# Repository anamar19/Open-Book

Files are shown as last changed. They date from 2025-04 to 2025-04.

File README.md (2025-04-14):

# 1. Block Diagram #


# 2. Bill of Materials (BOM) #
| Ref | Component | Link | Datasheet |
|-----|---|---|---|
| J2 | USB4110-GF-A | [LINK](https://ro.mouser.com/ProductDetail/GCT/USB4110-GF-A?qs=KUoIvG%2F9IlYiZvIXQjyJeA%3D%3D) | [DATASHEET](https://ro.mouser.com/datasheet/2/837/GCT_USB4110_Product_Drawing___20k_cycles-3455479.pdf) |
| D1 | USBLC6-2SC6Y |[LINK](https://ro.mouser.com/ProductDetail/STMicroelectronics/USBLC6-2SC6Y?qs=gNDSiZmRJS%2FOgDexvXkdow%3D%3D) | [DATASHEET](https://ro.mouser.com/datasheet/2/389/usblc6_2sc6y-1852505.pdf) |
| PFMF.050.2 | PFMF.050.2 | [LINK](https://ro.mouser.com/ProductDetail/Schurter/PFMF.010.2?qs=1auRipcfynCnJdD0clLSNw%3D%3D) | [DATASHEET](https://ro.mouser.com/datasheet/2/358/typ_PFMF-1275918.pdf) |
| C | C0402 | [LINK](https://ro.mouser.com/ProductDetail/KEMET/C0402C475K8PACTU?qs=ulEaXIWI0c9ebKRT3r3htg%3D%3D) | [DATASHEET](https://ro.mouser.com/datasheet/2/447/KEM_C1006_X5R_SMD-3316465.pdf) |
| R | CR0402 | [LINK](https://ro.mouser.com/ProductDetail/Bourns/CR0402-FX-78R7GLF?qs=ePR1ZvdkOKLVu%2FTT5yAHeA%3D%3D) |[DATASHEET](https://ro.mouser.com/datasheet/2/54/cr-1858361.pdf) |
| Q1 | DMG2305UX-7 | [LINK](https://ro.mouser.com/ProductDetail/Diodes-Incorporated/DMG2305UX-7?qs=L1DZKBg7t5F%2FNBHrjfxC%252Bg%3D%3D) | [DATASHEET](https://www.diodes.com/assets/Datasheets/DMG2305UX.pdf) |
| D2 | SD0805S020S1R0 | [LINK](https://eu.mouser.com/ProductDetail/KYOCERA-AVX/SD0805S020S1R0?qs=jCA%252BPfw4LHbpkAoSnwrdjw%3D%3D) | [DATASHEET](https://eu.mouser.com/datasheet/2/40/schottky-3165252.pdf) |
| C3 | F910J107MBAAJ6 | [LINK](https://eu.mouser.com/ProductDetail/KYOCERA-AVX/F910J107MBAAJ6?qs=PqoDHHvF649LraCA%2FjeGXg%3D%3D) | [DATASHEET](https://eu.mouser.com/datasheet/2/40/F91_AJ6-3162641.pdf) |
| IC1 | BD5229G-TR | [LINK](https://ro.mouser.com/ProductDetail/ROHM-Semiconductor/BD5229G-TR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) | [DATASHEET](https://fscdn.rohm.com/en/products/databook/datasheet/ic/power/voltage_detector/bd52xxg-e.pdf) |
| J4 | 112A-TAAR-R03 | [LINK](https://store.comet.srl.ro/Catalogue/Product/43497/) |[DATASHEET](https://www.attend.com.tw/data/download/file/112A-TAAR-R03.rar) |
| U2 | ESP32-C6-WROOM-1-N8 | [LINK](https://componentsearchengine.com/prices/ESP32-C6-WROOM-1-N8?manufacturer=Espressif%20Systems) | [DATASHEET](https://www.espressif.com/sites/default/files/documentation/esp32-c6-wroom-1_wroom-1u_datasheet_en.pdf) |
| U4 | MAX17048G+T10 | [LINK](https://ro.mouser.com/ProductDetail/Analog-Devices-Maxim-Integrated/MAX17048G%2bT10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) | [DATASHEET](https://ro.mouser.com/datasheet/2/609/MAX17048_MAX17049-3469099.pdf) |
| BUTTON | KMR221GULCLFS | [LINK](https://ro.mouser.com/ProductDetail/CK/KMR221GULCLFS?qs=u2NJ%252B70r0goBXaNk7IrU0Q%3D%3D) | [DATASHEET](https://www.ckswitches.com/media/1479/kmr2.pdf )|
| IC5 | BD5229G-TR | [LINK](https://ro.mouser.com/ProductDetail/ROHM-Semiconductor/BD5229G-TR?qs=4kLU8WoGk0vvnhrrYwdszw%3D%3D)  | [DATASHEET](https://fscdn.rohm.com/en/products/databook/datasheet/ic/power/voltage_detector/bd52xxg-e.pdf) |
| MCP | MCP73831T-2ACI/OT | [LINK](https://ro.mouser.com/ProductDetail/Microchip-Technology/MCP73831T-2ACI-OT?qs=yUQqVecv4qvbBQBGbHx0Mw%3D%3D)) | [DATASHEET](https://ro.mouser.com/datasheet/2/268/MCP73831_Family_Data_Sheet_DS20001984H-3441711.pdf)|
| Q3 | SI1308EDL-T1-GE3 | [LINK](https://componentsearchengine.com/prices/Si1308EDL-T1-GE3?manufacturer=Vishay) | [DATASHEET](https://componentsearchengine.com/Datasheets/1/SI1308EDL-T1-GE3.pdf) |
| SENSOR2 | BME680 | [LINK](https://ro.mouser.com/ProductDetail/Bosch-Sensortec/BME680?qs=v271MhAjFHjo0yA%2FC4OnDQ%3D%3D)  | [DATASHEET](https://ro.mouser.com/datasheet/2/783/BST_BME680_DS001-1509608.pdf) |
| SJ1 | CJS-1201B | [LINK](https://ro.mouser.com/ProductDetail/Nidec-Components/CJS-1201B?qs=XeJtXLiO41SSSa2Z7HG9Iw%3D%3D)  | [DATASHEET](https://ro.mouser.com/datasheet/2/972/cjs-1827353.pdf) |
| L1 |  LQW18ANR18J00D| [LINK](https://ro.mouser.com/ProductDetail/Murata-Electronics/LQW18ANR18J00D?qs=up2IPS6mPfZTlRcpK55RLw%3D%3D)  | [DATASHEET](https://ro.mouser.com/datasheet/2/281/JELF243A_0024-1380895.pdf) |
| D3 | MBR0530T3G | [LINK](https://ro.mouser.com/ProductDetail/onsemi/MBR0530T3G?qs=3JMERSakebpEmdUS6GetdQ%3D%3D)  | [DATASHEET](https://www.onsemi.com/PowerSolutions/product.do?id=MBR0530T3G) |
| J1 | FH34SRJ-24S-0.5SH_99_ | [LINK](https://ro.mouser.com/ProductDetail/Hirose-Connector/FH34SRJ-24S-0.5SH99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)  | [DATASHEET](https://ro.mouser.com/datasheet/2/185/FH34SRJ_24S_0_5SH_99__CL0580_1255_6_99_2DDrawing_0-1615044.pdf) |
| U3 | DS3231SN# | [LINK](https://ro.mouser.com/ProductDetail/Analog-Devices-Maxim-Integrated/DS3231SN?qs=1eQvB6Dk1vhUlr8%2FOrV0Fw%3D%3D)  | [DATASHEET](https://ro.mouser.com/datasheet/2/609/DS3231-3421123.pdf) |
|C10_SUPERCAR | CPH3225A | [LINK](https://ro.mouser.com/ProductDetail/Seiko-Semiconductors/CPH3225A?qs=3etwrb1wR%252BhUOph6lAO7eg%3D%3D)  | [DATASHEET](https://ro.mouser.com/datasheet/2/360/Seiko_Instruments_MicroBattery_E_20230330_2024Jan_-3561061.pdf) |
| D8 | PGB1010603MR | [LINK](https://ro.mouser.com/ProductDetail/Littelfuse/PGB1010603MR?qs=gu7KAQ731URLg4GSnNNN7Q%3D%3D) | [DATASHEET](https://www.littelfuse.com/assetdocs/pulseguard-esd-suppressors-pgb1-datasheet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) |
| J3 | 4208| [LINK](https://ro.mouser.com/ProductDetail/Adafruit/4208?qs=PzGy0jfpSMtbScLbr0L5dw%3D%3D) | [DATASHEET](https://www.analog.com/media/en/technical-documentation/data-sheets/ada4570.pdf) |
| U1 | W25Q512JVEIQ | [LINK](https://ro.mouser.com/ProductDetail/Winbond/W25Q512JVEIQ?qs=l7cgNqFNU1jw6svr3at6tA%3D%3D) | [DATASHEET](https://ro.mouser.com/datasheet/2/949/Winbond_W25Q512JV_Datasheet-3240039.pdf) |

# 3. Funcționalități Hardware #

## 3.1. Componente, module și senzori ##

### ESP32-C6-WROOM-1-N8 ###
- microcontroler de bază care gestionează comunicațiile(SPI,I2C), controlează perifericele.
### USB C connector & ESD protection ###
- asigură alimentarea prin USB-C și protecție.
### LDO Voltage Regulator ###
- stabilizează tensiunea de 3.3V
### SD Card ###
- permite stocarea locală a fișierelor de configurare și a datelor.
### E-Paper Drive Circuit & Header ###
- generează semnale pentru controlul ecranului E-Paper și permite selectarea tipului de dispaly.
### Li-Po Battery Charging Controller ###
- încarcă bateria Li-Po și gestionează curentul de încărcare.
### Environmental Sensor  ###
- măsoară presiunea, temperatura, umiditatea și calitatea aerului.
### Voltage Supervisor + Reset & Boot / IO Button ###
- monitorizează tensiunea de alimentare și asigură resetarea sistemului.
### Li-Po Battery ###
- sursă de alimentare de rezervă, care permite funcționarea sistemului fără USB.
### RTC Module DS3231SN ###
- asigură funcționarea de ceas în timp real.
### External NORFlash64MB ###
- memorie secundară pentru stocarea datelor.

## 3.2. Specificații de comunicație ##
- SPI este folosit pentru NOR Flash, cardul SD și dispaly-ul E-Paper
- I2C este utilizat pentru senzorul BME688 și modulul DS3231SN
- UART este folosit pentru debugging
- Wi-Fi & Bluetooth LE sunt date de ESP32-C6 pentru conectivitate wireless.

## 3.3. Calcule de consum de energie ##
- ESP32-C6: consum în mod activ-aprox 80-240mA și în mod sleep-cam 1mA
- NOR Flash: consum la citire/scriere-5-15mA, iar în repaus-mai puțin de 10uA
- BM3688: consum în mod activ de 3.1mA, iar în mod sleep aprox 2.1uA
- LDO: eficiența depinde de diferența de tensiune (aprox 3.3V) și curentul total
- DS3231SN: consum de cca 150uA cu backup la baterie

  Bateria Li-Po poate menține sistemul destul de mult timp, de ordinul zilelor chiar, în funcție de capacitate și de cât de des se folosesc comunicațiile Wi-Fi/Bluetooth.

# 4. Pinii ESP32-C6 #
| Pin | Componentă | Motiv |
|-----|---|---|
| MOSI(IO6) | SPI MOSI către NOR Flash,SD Card și E-Paper | Transfer date către periferice SPI |
| MISO(IO7) | SPI MISO din NOR Flash,SD Card și E-Paper | Primire date către periferice SPI |
| SDA(IO14) | I2C SDA către BME688 și DS3231SN | Linia de date pentru I2C|
| SCL(IO15) | I2C SCL către BME688 și DS3231SN | Semnal de clock I2C |
| SCK(IO8) | SPI Clock | Semnal de clock SPI |
| CS1(IO9) |  Chip Select NOR Flash | Control dedicat pentru NOR Flash |
| CS2(IO10) |  Chip Select E-Paper Display | Control dedicat pentru Display |
| CS3(IO11) | Chip Select SD Card |  Control dedicat pentru SD Card |
| IO16,IO17 | UART,TX,RX(debug) | Debug serial și programare |
| IO21 | Control Boot/Reset | Butoane de reset și boot |
| 3V3(IO2) | - | Furnizează tensiunea de 3.3V pentru componente |
| GND | - | Referință pentru circuit |

# 5. Comentarii #
## 5.1. Design log și Randări PCB ##
Randări:
- există randări 3D ale PCB-ULUI care arată poziționarea corectă a componentelor pricipale: ESP32-C6, conectorul USB, senzorii
- carcasa este proiectată în Fusion 360
- bateria este proiectată, de asemenea, în Fusion 360
-  display-ul este luat din [link](https://grabcad.com/library/7-5in-e-ink-display-assortment-1) conform datasheet-ului

## 5.2. Așezarea Componentelor în Carcasă ##
- Conectorii Qwiic/ Stemma QT  sunt plasați la marfinea plăcii pentru a facilita atașarea rapidă a altor senzori
- Bateria Li-Po e plasată direct lângă PCB pentru a economisi spațiu
- Microcontrolerul ESP32 e poziționat la marginea PCB-ului pentru a reduce interferențele la antenă, iar din această cauză a fost tăiat și planul de masă li placa PCB în jurul antenei

## 5.3. Decizii luate ##
Am acceptat cele 7 erori de overlap pentru că traseele de putere, fiind rutate cu 0.3mm, se intersecteaza pe padul B9:VBUS și A4:VUSB, acestea fiind foarte apropiate una de alta.  Mai am 2 erori de Board Outline Clearance la aceeasi componenta, pe care le-am acceptat pentru ca așa este configurată componenta USB4110-GF-A, adica din cauza dimensiunii gaurilor.

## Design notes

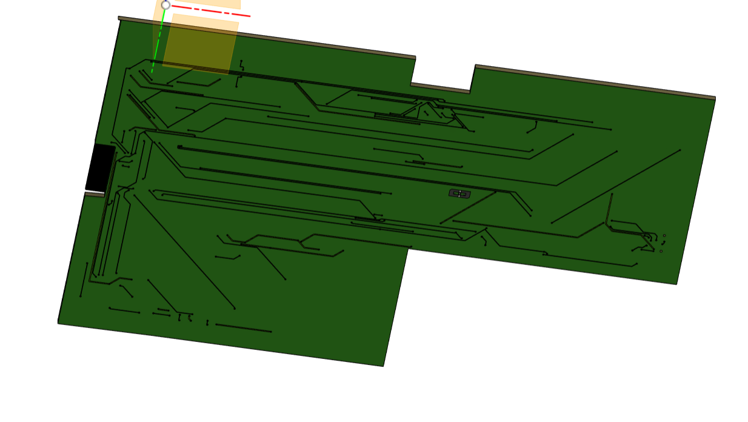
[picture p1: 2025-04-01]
Images/PCB2.png

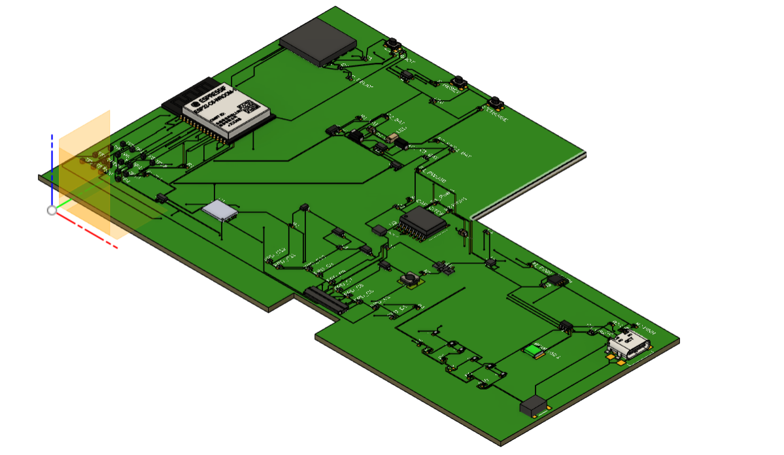
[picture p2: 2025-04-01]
Images/PCB1.png

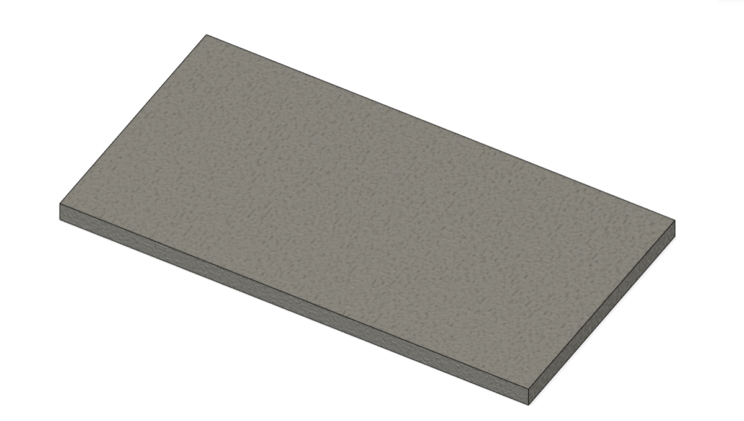
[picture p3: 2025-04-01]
Images/Battery.png

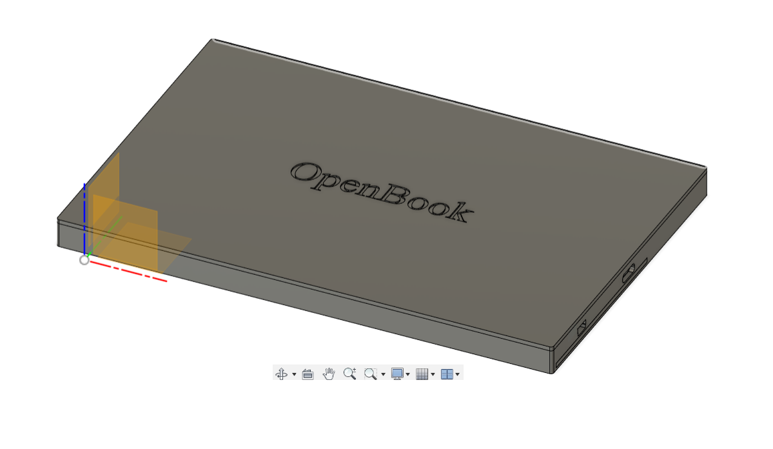
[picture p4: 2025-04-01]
Images/Device2.png

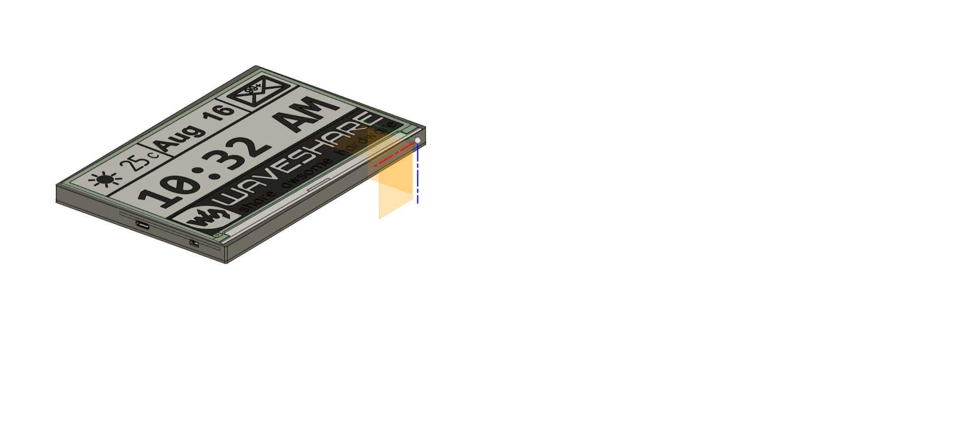
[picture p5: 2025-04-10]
Images/Device1.png

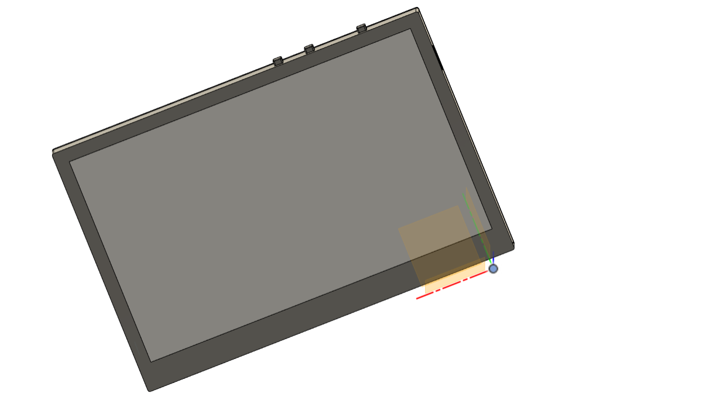
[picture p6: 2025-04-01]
Images/Dispaly.png

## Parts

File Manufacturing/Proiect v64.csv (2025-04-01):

Qty | Value | Device | Package | Parts | Description | ARROW_PART_NUMBER | ARROW_PRICE-STOCK | AVAILABILITY | CATEGORY | CENTROID_NOT_SPECIFIED | CHECK_PRICES | COPYRIGHT | DATASHEET | DESCRIPTION | DIGIKEY_DESCRIPTION | DIGIKEY_PART_NUMBER | HEIGHT | LEAD_FREE | MANUFACTURER | MANUFACTURER_NAME | MANUFACTURER_PART_NUMBER | MF | MFR_NAME | MOUSER_PART_NUMBER | MOUSER_PRICE-STOCK | MP | MPN | OPERATING_TEMPERATURE | PACKAGE | PACKAGE_SIZE | PACKAGE_TYPE | PART_STATUS | POPULARITY | PREFIX | PRICE | PROD_ID | PURCHASE-URL | ROHS | SERIES | SNAPEDA_LINK | SPICEMODEL | SPICEPREFIX | SUBCATEGORY | TEMPERATURE_RANGE_HIGH | TEMPERATURE_RANGE_LOW | THERMALLOSS | TOLERANCE | TP_SIGNAL_NAME | TYPE | VALUE | VOLTAGE_RATING
1 |  | ADAFRUIT_LEDCHIP-LED0603 | ADAFRUIT_CHIP-LED0603 | CHG_LED | LED
1 |  | SJ | SJ | SJ1 | SMD solder JUMPER |  |  |  |  |  |  |  |  |  |  |  |  |  |  |  |  |  |  |  |  |  |  |  |  |  |  |  | 3
1 | 0.1uF/50V | ESP32_WROVER_EAGLE-LTSPICE_CC0402 | ESP32_WROVER_EAGLE-LTSPICE_C0402 | EPD_C5 | CAPACITOR, European symbol |  |  |  |  |  |  |  |  |  |  |  |  |  |  |  |  |  |  |  |  |  |  |  |  |  |  |  |  |  |  |  |  |  |  |  | NONE | C
1 | 0.47 | ESP32_WROVER_EAGLE-LTSPICE_RR0402 | ESP32_WROVER_EAGLE-LTSPICE_R0402 | R3 | RESISTOR, European symbol |  |  |  |  |  |  |  |  |  |  |  |  |  |  |  |  |  |  |  |  |  |  |  |  |  |  |  |  |  |  |  |  |  |  |  | NONE | R
1 | 100k | ESP32_WROVER_EAGLE-LTSPICE_RR0402 | ESP32_WROVER_EAGLE-LTSPICE_R0402 | R1_PWUSB | RESISTOR, European symbol |  |  |  |  |  |  |  |  |  |  |  |  |  |  |  |  |  |  |  |  |  |  |  |  |  |  |  |  |  |  |  |  |  |  |  | NONE | R
2 | 100nF | C_CHIP-0402(1005-METRIC) | CAPC1005X60 | C4_USB, C9 | Capacitor - Generic |  |  |  | Capacitor |  |  |  |  |  |  |  |  |  |  |  |  |  |  |  |  |  |  |  |  | 0402 | SMD |  |  |  |  |  |  |  |  |  |  |  | Ceramic Capacitors |  |  |  |  |  | MLCC
1 | 100nF | EAGLE-LTSPICE_CC0402 | EAGLE-LTSPICE_C0402 | C8 | CAPACITOR, European symbol |  |  |  |  |  |  |  |  |  |  |  |  |  |  |  |  |  |  |  |  |  |  |  |  |  |  |  |  |  |  |  |  |  |  |  | NONE | C
5 | 100nF | ESP32_WROVER_EAGLE-LTSPICE_CC0402 | ESP32_WROVER_EAGLE-LTSPICE_C0402 | C1, C2, C6, C10, C_DELAY | CAPACITOR, European symbol |  |  |  |  |  |  |  |  |  |  |  |  |  |  |  |  |  |  |  |  |  |  |  |  |  |  |  |  |  |  |  |  |  |  |  | NONE | C
1 | 100uF TANT | C-POL_TANTALUM-1206(3216-METRIC) | CAPMP3216X180N | C3 | Capacitor Polarised - Generic |  |  |  | Capacitor |  |  |  |  |  |  |  |  |  |  |  |  |  |  |  |  |  |  |  |  | 1206 | SMD |  |  |  |  |  |  |  |  |  |  |  | Tantalum Capacitors |  |  |  |  |  | Polymer Capacitors
16 | 10k | ESP32_WROVER_EAGLE-LTSPICE_RR0402 | ESP32_WROVER_EAGLE-LTSPICE_R0402 | R1, R1_PINH, R1_PINH1, R2-PINH, R2-PINH1, R4, R5, R6, R7, R8, R9, R10, R_BOOT, R_CHANGE, R_CL1, R_RESET | RESISTOR, European symbol |  |  |  |  |  |  |  |  |  |  |  |  |  |  |  |  |  |  |  |  |  |  |  |  |  |  |  |  |  |  |  |  |  |  |  | NONE | R
1 | 10uF | EAGLE-LTSPICE_CC0402 | EAGLE-LTSPICE_C0402 | C7 | CAPACITOR, European symbol |  |  |  |  |  |  |  |  |  |  |  |  |  |  |  |  |  |  |  |  |  |  |  |  |  |  |  |  |  |  |  |  |  |  |  | NONE | C
1 | 112A-TAAR-R03_ATTEND | 112A-TAAR-R03_ATTEND | 112ATAARR03ATTEND | J4 | Micro SD Card Socket, Push-Push Type, Top Mount, SMT, H=1.83mm, 10u |  |  |  |  |  |  |  |  | Micro SD Card Socket | Push-Push Type | Top Mount | SMT | H=1.83mm | 10u |  |  | 1.9mm |  |  | ATTEND | 112A-TAAR-R03 ATTEND
1 | 15 | ESP32_WROVER_EAGLE-LTSPICE_RR0402 | ESP32_WROVER_EAGLE-LTSPICE_R0402 | R_CAPACITOR | RESISTOR, European symbol |  |  |  |  |  |  |  |  |  |  |  |  |  |  |  |  |  |  |  |  |  |  |  |  |  |  |  |  |  |  |  |  |  |  |  | NONE | R
1 | 1uF | ESP32_WROVER_EAGLE-LTSPICE_CC0402 | ESP32_WROVER_EAGLE-LTSPICE_C0402 | C5 | CAPACITOR, European symbol |  |  |  |  |  |  |  |  |  |  |  |  |  |  |  |  |  |  |  |  |  |  |  |  |  |  |  |  |  |  |  |  |  |  |  | NONE | C
9 | 1uF/50V | ESP32_WROVER_EAGLE-LTSPICE_CC0402 | ESP32_WROVER_EAGLE-LTSPICE_C0402 | EPD_C1, EPD_C2, EPD_C6, EPD_C7, EPD_C8, EPD_C9, EPD_C10, EPD_C11, EPD_C12 | CAPACITOR, European symbol |  |  |  |  |  |  |  |  |  |  |  |  |  |  |  |  |  |  |  |  |  |  |  |  |  |  |  |  |  |  |  |  |  |  |  | NONE | C
1 | 2.2 | ESP32_WROVER_EAGLE-LTSPICE_RR0402 | ESP32_WROVER_EAGLE-LTSPICE_R0402 | R2 | RESISTOR, European symbol |  |  |  |  |  |  |  |  |  |  |  |  |  |  |  |  |  |  |  |  |  |  |  |  |  |  |  |  |  |  |  |  |  |  |  | NONE | R
1 | 200 | ESP32_WROVER_EAGLE-LTSPICE_RR0402 | ESP32_WROVER_EAGLE-LTSPICE_R0402 | R1_BAT | RESISTOR, European symbol |  |  |  |  |  |  |  |  |  |  |  |  |  |  |  |  |  |  |  |  |  |  |  |  |  |  |  |  |  |  |  |  |  |  |  | NONE | R
2 | 20V/4.2A/52mO/1.4W | ESP32_WROVER_SPARKFUN-DISCRETESEMI_MOSFET_PCH-DMG2305UX-7 | ESP32_WROVER_SPARKFUN-DISCRETESEMI_SOT23-3 | Q1, Q2 | P-channel MOSFETs |  |  |  |  |  |  |  |  |  |  |  |  |  |  |  |  |  |  |  |  |  |  |  |  |  |  |  |  |  |  | TRAN-14388 |  |  |  |  |  |  |  |  |  |  |  |  |  | 20V/4.2A/52mO/1.4W
1 | 2k | ESP32_WROVER_EAGLE-LTSPICE_RR0402 | ESP32_WROVER_EAGLE-LTSPICE_R0402 | R2_BAT | RESISTOR, European symbol |  |  |  |  |  |  |  |  |  |  |  |  |  |  |  |  |  |  |  |  |  |  |  |  |  |  |  |  |  |  |  |  |  |  |  | NONE | R
2 | 4.7uF | C_CHIP-0402(1005-METRIC) | CAPC1005X60 | C1_BAT1, C5_USB | Capacitor - Generic |  |  |  | Capacitor |  |  |  |  |  |  |  |  |  |  |  |  |  |  |  |  |  |  |  |  | 0402 | SMD |  |  |  |  |  |  |  |  |  |  |  | Ceramic Capacitors |  |  |  |  |  | MLCC
1 | 4.7uF | C_TANTALUM-1206(3216-METRIC) | CAPM3216X180 | C1_BAT2 | Capacitor - Generic |  |  |  | Capacitor |  |  |  |  |  |  |  |  |  |  |  |  |  |  |  |  |  |  |  |  | 1206 | SMD |  |  |  |  |  |  |  |  |  |  |  | Tantalum Capacitors |  |  |  |  |  | Polymer Capacitors
2 | 4.7uF | ESP32_WROVER_EAGLE-LTSPICE_CC0402 | ESP32_WROVER_EAGLE-LTSPICE_C0402 | C1_BAT, C2_BAT | CAPACITOR, European symbol |  |  |  |  |  |  |  |  |  |  |  |  |  |  |  |  |  |  |  |  |  |  |  |  |  |  |  |  |  |  |  |  |  |  |  | NONE | C
1 | 4.7uF/25V | EAGLE-LTSPICE_CC0402 | EAGLE-LTSPICE_C0402 | C4 | CAPACITOR, European symbol |  |  |  |  |  |  |  |  |  |  |  |  |  |  |  |  |  |  |  |  |  |  |  |  |  |  |  |  |  |  |  |  |  |  |  | NONE | C
2 | 5k1 | ESP32_WROVER_EAGLE-LTSPICE_RR0402 | ESP32_WROVER_EAGLE-LTSPICE_R0402 | R2-USB, R2-USB1 | RESISTOR, European symbol |  |  |  |  |  |  |  |  |  |  |  |  |  |  |  |  |  |  |  |  |  |  |  |  |  |  |  |  |  |  |  |  |  |  |  | NONE | R
1 | 68uH | 744043680IND_4828-WE-TPC_WRE | IND_4828-WE-TPC_WRE | L1 |  |  |  |  |  |  |  | Copyright (C) 2024 Ultra Librarian. All rights reserved. |  |  |  |  |  |  |  |  | 744043680 |  | Wurth Electronics
1 | BD5229G-TR | BD5229G-TR | SOT95P280X125-5N | IC5 | Voltage Detector with Adjustable Delay Time: CMOS processes are utilized to develop high precision, low current consumption CMOS reset ICs that allow arbitrary setting of the delay time. The extensive lineup includes both Nch Open Drain and CMOS output types in a wide range of detection voltages (from 2.3V to 6.0V, in 0.1V steps), enabling selection of the ideal solution based on customer requirements. In addition, the entire series is of course both lead-free and RoHS-compliant. |  |  |  |  |  |  |  |  | Voltage Detector with Adjustable Delay Time: CMOS processes are utilized to develop high precision | low current consumption CMOS reset ICs that allow arbitrary setting of the delay time. The extensive lineup includes both Nch Open Drain and CMOS output types in a wide range of detection voltages (from 2.3V to 6.0V | in 0.1V steps) | enabling selection of the ideal solution based on customer requirements. In addition | the entire series is of course both lead-free and RoHS-compliant. |  |  | 1.25mm |  |  | ROHM Semiconductor | BD5229G-TR |  |  | 755-BD5229G-TR | https://www.mouser.co.uk/ProductDetail/ROHM-Semiconductor/BD5229G-TR?qs=4kLU8WoGk0vvnhrrYwdszw%3D%3D
3 | BUTTON_CUSYOMV1 | BUTTON_CUSYOMV1 | MYBUTTON | BOOT_BUTTON, CHANGE_BUTTON, RESET_BUTTON
1 | CPH3225A | CPH3225A | CAPCP3225X100N | C10_SUPERCAP | Cap 0.011F 3.3V 1210 Flat Check availability |  |  | Not in stock |  |  | https://www.snapeda.com/parts/CPH3225A/Seiko+Instruments/view-part/?ref=eda |  |  | 11 mF (EDLC) Supercapacitor 3.3 V 1210 (3225 Metric) - - |  |  |  |  |  |  |  | Seiko Instruments |  |  |  | CPH3225A |  |  | 1210 Seiko |  |  |  |  |  | None |  | https://www.snapeda.com/api/url_track_click_mouser/?unipart_id=562593&manufacturer=Seiko Instruments&part_name=CPH3225A&search_term=None |  |  | https://www.snapeda.com/parts/CPH3225A/Seiko+Instruments/view-part/?ref=snap
1 | DS3231SN# | DS3231SN# | SOIC127P1032X265-16N | U3 | Real Time Clock Serial 16-Pin SOIC W T/R Check availability |  |  | In Stock |  |  | https://www.snapeda.com/parts/DS3231SN%23/Analog+Devices/view-part/?ref=eda |  |  | Extremely Accurate I²C-Integrated RTC/TCXO/Crystal |  |  |  |  |  |  |  | Analog Devices |  |  |  | DS3231SN# |  |  | SOIC-16 Maxim |  |  |  |  |  | None |  | https://www.snapeda.com/api/url_track_click_mouser/?unipart_id=99048&manufacturer=Analog Devices&part_name=DS3231SN#&search_term=None |  |  | https://www.snapeda.com/parts/DS3231SN%23/Analog+Devices/view-part/?ref=snap
1 | ESP32-C6-WROOM-1-N8 | ESP32-C6-WROOM-1-N8 | XCVR_ESP32-C6-WROOM-1-N8 | U2 | Check availability |  |  | In Stock |  |  | https://www.snapeda.com/parts/ESP32-C6-WROOM-1-N8/Espressif+Systems/view-part/?ref=eda |  |  | Multiprotocol Modules ESP32-C6 module | Wi-Fi 6 in 2.4 GHz band | Bluetooth 5 | Zigbee 3.0 and Thread. ESP34-WROOM Compatible - ENGINEERING SAMPLE |  |  |  |  |  |  |  | Espressif Systems |  |  |  | ESP32-C6-WROOM-1-N8 |  |  | None |  |  |  |  |  | None |  |  |  |  | https://www.snapeda.com/parts/ESP32-C6-WROOM-1-N8/Espressif+Systems/view-part/?ref=snap
1 | ESP32C6_VARISTORCN1812 | ESP32C6_VARISTORCN1812 | ESP32C6_VARISTOR_CT/CN1812 | PFMF.050.1 | VARISTOR |  |  |  |  |  |  |  |  |  |  |  |  |  |  |  |  |  |  |  |  |  |  |  |  |  |  |  | 0
2 | ESP32_WROVER_AVX---SD0805S020S1R0_AVX_SD0805S020S1R0_0_0AVX_SD0805S020S1R0_0_0 | ESP32_WROVER_AVX---SD0805S020S1R0_AVX_SD0805S020S1R0_0_0AVX_SD0805S020S1R0_0_0 | ESP32_WROVER_AVX---SD0805S020S1R0_AVX_SD0805S020S1R0_0 | D2, D7 | Schottky Barrier Rectifier Diode |  |  |  |  | No |  |  | http://datasheets.avx.com/schottky.pdf |  | DIODE SCHOTTKY 20V 1A 0805 | 478-7800-1-ND |  | yes |  |  |  | AVX |  | 581-SD0805S020S1R0 |  |  |  |  | 0805 (2012 metric) |  |  |  |  | D |  |  |  | yes |  |  |  |  |  | +125°C | -55°C
1 | ESP32_WROVER_BME680_BME680 | ESP32_WROVER_BME680_BME680 | ESP32_WROVER_BME680_PSON80P300X300X100-8N | SENSOR2 | Integrated Environmental Unit |  |  | Unavailable |  |  |  |  |  | Integrated Environmental Unit |  |  |  |  |  |  |  | Bosch Sensortec |  |  |  | BME680 |  |  | LGA-8 Bosch Tools |  |  |  |  |  | None
1 | ESP32_WROVER_SPARKFUN-IC-POWER_MCP73831 | ESP32_WROVER_SPARKFUN-IC-POWER_MCP73831 | ESP32_WROVER_SPARKFUN-IC-POWER_SOT23-5 | MCP73831 | MCP73831T Li-Ion, Li-Pol Controller |  |  |  |  |  |  |  |  |  |  |  |  |  |  |  |  |  |  |  |  |  |  |  |  |  |  |  |  |  |  | IC-09995
1 | FH34SRJ-24S-0.5SH_99_ | FH34SRJ-24S-0.5SH_99_ | FH34SRJ24S05SH99 | J1 | (0.50mm) Surface Mount, Right Angle |  |  |  |  |  |  |  |  | 24 Position FFC | FPC Connector Contacts | (0.50mm) Surface Mount | Right Angle |  |  | 1.1mm |  |  | Hirose | FH34SRJ-24S-0.5SH(99) |  |  | 798-FH34SRJ24S05SH99 | https://www.mouser.co.uk/ProductDetail/Hirose-Connector/FH34SRJ-24S-0.5SH99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
1 | MAX17048G+T10 | MAX17048G+T10 | SON50P200X200X80-9N | U4 | Check availability |  |  | In Stock |  |  | https://www.snapeda.com/parts/MAX17048G+T10/Analog+Devices/view-part/?ref=eda |  |  | 3µA 1-Cell/2-Cell Fuel Gauge with ModelGauge |  |  |  |  |  |  |  | Analog Devices |  |  |  | MAX17048G+T10 |  |  | TDFN-8 Maxim |  |  |  |  |  | None |  | https://www.snapeda.com/api/url_track_click_mouser/?unipart_id=329239&manufacturer=Analog Devices&part_name=MAX17048G+T10&search_term=None |  |  | https://www.snapeda.com/parts/MAX17048G+T10/Analog+Devices/view-part/?ref=snap
3 | MBR0530 | MBR0530 | SOD3716X135N | D3, D4, D5 | ON SEMICONDUCTOR - MBR0530 - DIODE, SCHOTTKY, 0.5A, 30V, SOD-123 |  |  | In Stock |  |  | https://www.snapeda.com/parts/MBR0530/Onsemi/view-part/?ref=eda |  |  | Diode Schottky 30 V 500mA Surface Mount SOD-123 |  |  |  |  |  |  |  | ON Semiconductor |  |  |  | MBR0530 |  |  | SOD-123-2 ON Semiconductor |  |  |  |  |  | None |  | https://www.snapeda.com/api/url_track_click_mouser/?unipart_id=179458&manufacturer=ON Semiconductor&part_name=MBR0530&search_term=None |  |  | https://www.snapeda.com/parts/MBR0530/Onsemi/view-part/?ref=snap
6 | PGB1010603MR | PGB1010603MR | DIOC1608X36N | D6, D8, D9, D10, D11, D12 | Check availability |  |  | In Stock |  |  | https://www.snapeda.com/parts/PGB1010603MR/Littelfuse/view-part/?ref=eda |  |  | 150V (Typ) Clamp - Ipp Tvs Diode Surface Mount 0603 (1608 Metric) |  |  |  |  |  |  |  | Littelfuse Inc. |  |  |  | PGB1010603MR |  |  | 0603 Littelfuse Inc. |  |  |  |  |  | None |  | https://www.snapeda.com/api/url_track_click_mouser/?unipart_id=5659453&manufacturer=Littelfuse Inc.&part_name=PGB1010603MR&search_term=None |  |  | https://www.snapeda.com/parts/PGB1010603MR/Littelfuse/view-part/?ref=snap
1 | QWIIC_RIGHT_ANGLE | QWIIC_CONNECTORJS-1MM | JST04_1MM_RA | J3 | SparkFun I2C Standard Qwiic Connector |  |  |  |  |  |  |  |  |  |  |  |  |  |  |  |  |  |  |  |  |  |  |  |  |  |  |  |  |  |  | CONN-13694 |  |  |  |  |  |  |  |  |  |  |  |  |  | QWIIC_RIGHT_ANGLE
1 | SAMACSYS_PARTS_USB4110-GF-A | SAMACSYS_PARTS_USB4110-GF-A | SAMACSYS_PARTS_USB4110GFA | J2 | CONN USB 2.0 TYPE-C R/A SMT |  |  |  |  |  |  |  |  | CONN USB 2.0 TYPE-C R/A SMT |  |  | 3.26mm |  |  | GCT (GLOBAL CONNECTOR TECHNOLOGY) | USB4110-GF-A |  |  | 640-USB4110-GF-A | https://www.mouser.co.uk/ProductDetail/GCT/USB4110-GF-A?qs=KUoIvG%2F9IlYiZvIXQjyJeA%3D%3D
1 | SI1308EDL-T1-GE3 | SI1308EDL-T1-GE3 | SOT65P210X110-3N | Q3 | MOSFET N-Ch 30V 1.5A TrenchFET SC70 Vishay Si1308EDL-T1-GE3 N-channel MOSFET Transistor, 1.5 A, 30 V, 3-Pin SC-70 | SI1308EDL-T1-GE3 | https://www.arrow.com/en/products/si1308edl-t1-ge3/vishay?utm_currency=USD&region=nac |  |  |  |  |  |  | MOSFET N-Ch 30V 1.5A TrenchFET SC70 Vishay Si1308EDL-T1-GE3 N-channel MOSFET Transistor | 1.5 A | 30 V | 3-Pin SC-70 |  |  | 1.1mm |  |  | Vishay | Si1308EDL-T1-GE3 |  |  | 78-SI1308EDL-T1-GE3 | https://www.mouser.co.uk/ProductDetail/Vishay-Semiconductors/SI1308EDL-T1-GE3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
17 | TPB1,27 | TPB1,27 | B1,27 | TP1, TP2, TP3, TP4, TP5, TP6, TP7, TP8, TP9, TP10, TP11, TP12, TP13, TP14, TP15, TP16, TP17 | Test pad |  |  |  |  |  |  |  |  |  |  |  |  |  |  |  |  |  |  |  |  |  |  |  |  |  |  |  | 19
1 | USBLC6-2SC6Y | USBLC6-2SC6Y | SOT95P280X145-6N | D1 | Low Cap. ESD Protection Auto SOT-23-6 STMicroelectronics USBLC6-2SC6Y, Dual Uni-Directional TVS Diode Array, 6-Pin SOT-23 |  |  | In Stock |  |  | https://www.snapeda.com/parts/USBLC6-2SC6Y/STMicroelectronics/view-part/?ref=eda |  |  | 17V Clamp 5A (8/20µs) Ipp Tvs Diode Surface Mount SOT-23-6 |  |  |  |  |  |  |  | STMicroelectronics |  |  |  | USBLC6-2SC6Y |  |  | SOT-23-6 STMicroelectronics |  |  |  |  |  | None |  |  |  |  | https://www.snapeda.com/parts/USBLC6-2SC6Y/STMicroelectronics/view-part/?ref=snap
1 | W25Q512JVEIQ | W25Q512JVEIQ | SON127P600X800X80-9N | U1 | Check availability |  |  | In Stock |  |  | https://www.snapeda.com/parts/W25Q512JVEIQ/Winbond+Electronics/view-part/?ref=eda |  |  | FLASH - NOR Memory IC 512Mb (64M x 8) SPI - Quad I/O 133 MHz 8-WSON (8x6) |  |  |  |  |  |  |  | Winbond Electronics |  |  |  | W25Q512JVEIQ |  |  | Package |  |  |  |  |  | None |  |  |  |  | https://www.snapeda.com/parts/W25Q512JVEIQ/Winbond+Electronics/view-part/?ref=snap
1 | XC6220A331MR-G | XC6220A331MR-G | SOT95P280X120-5N | IC1 | LDO Voltage Regulators |  |  |  |  |  |  |  |  | LDO Voltage Regulators |  |  | 1.2mm |  |  | Torex | XC6220A331MR-G |  |  | 865-XC6220A331MR-G | https://www.mouser.co.uk/ProductDetail/Torex-Semiconductor/XC6220A331MR-G?qs=AsjdqWjXhJ8ZSWznL1J0gg%3D%3D

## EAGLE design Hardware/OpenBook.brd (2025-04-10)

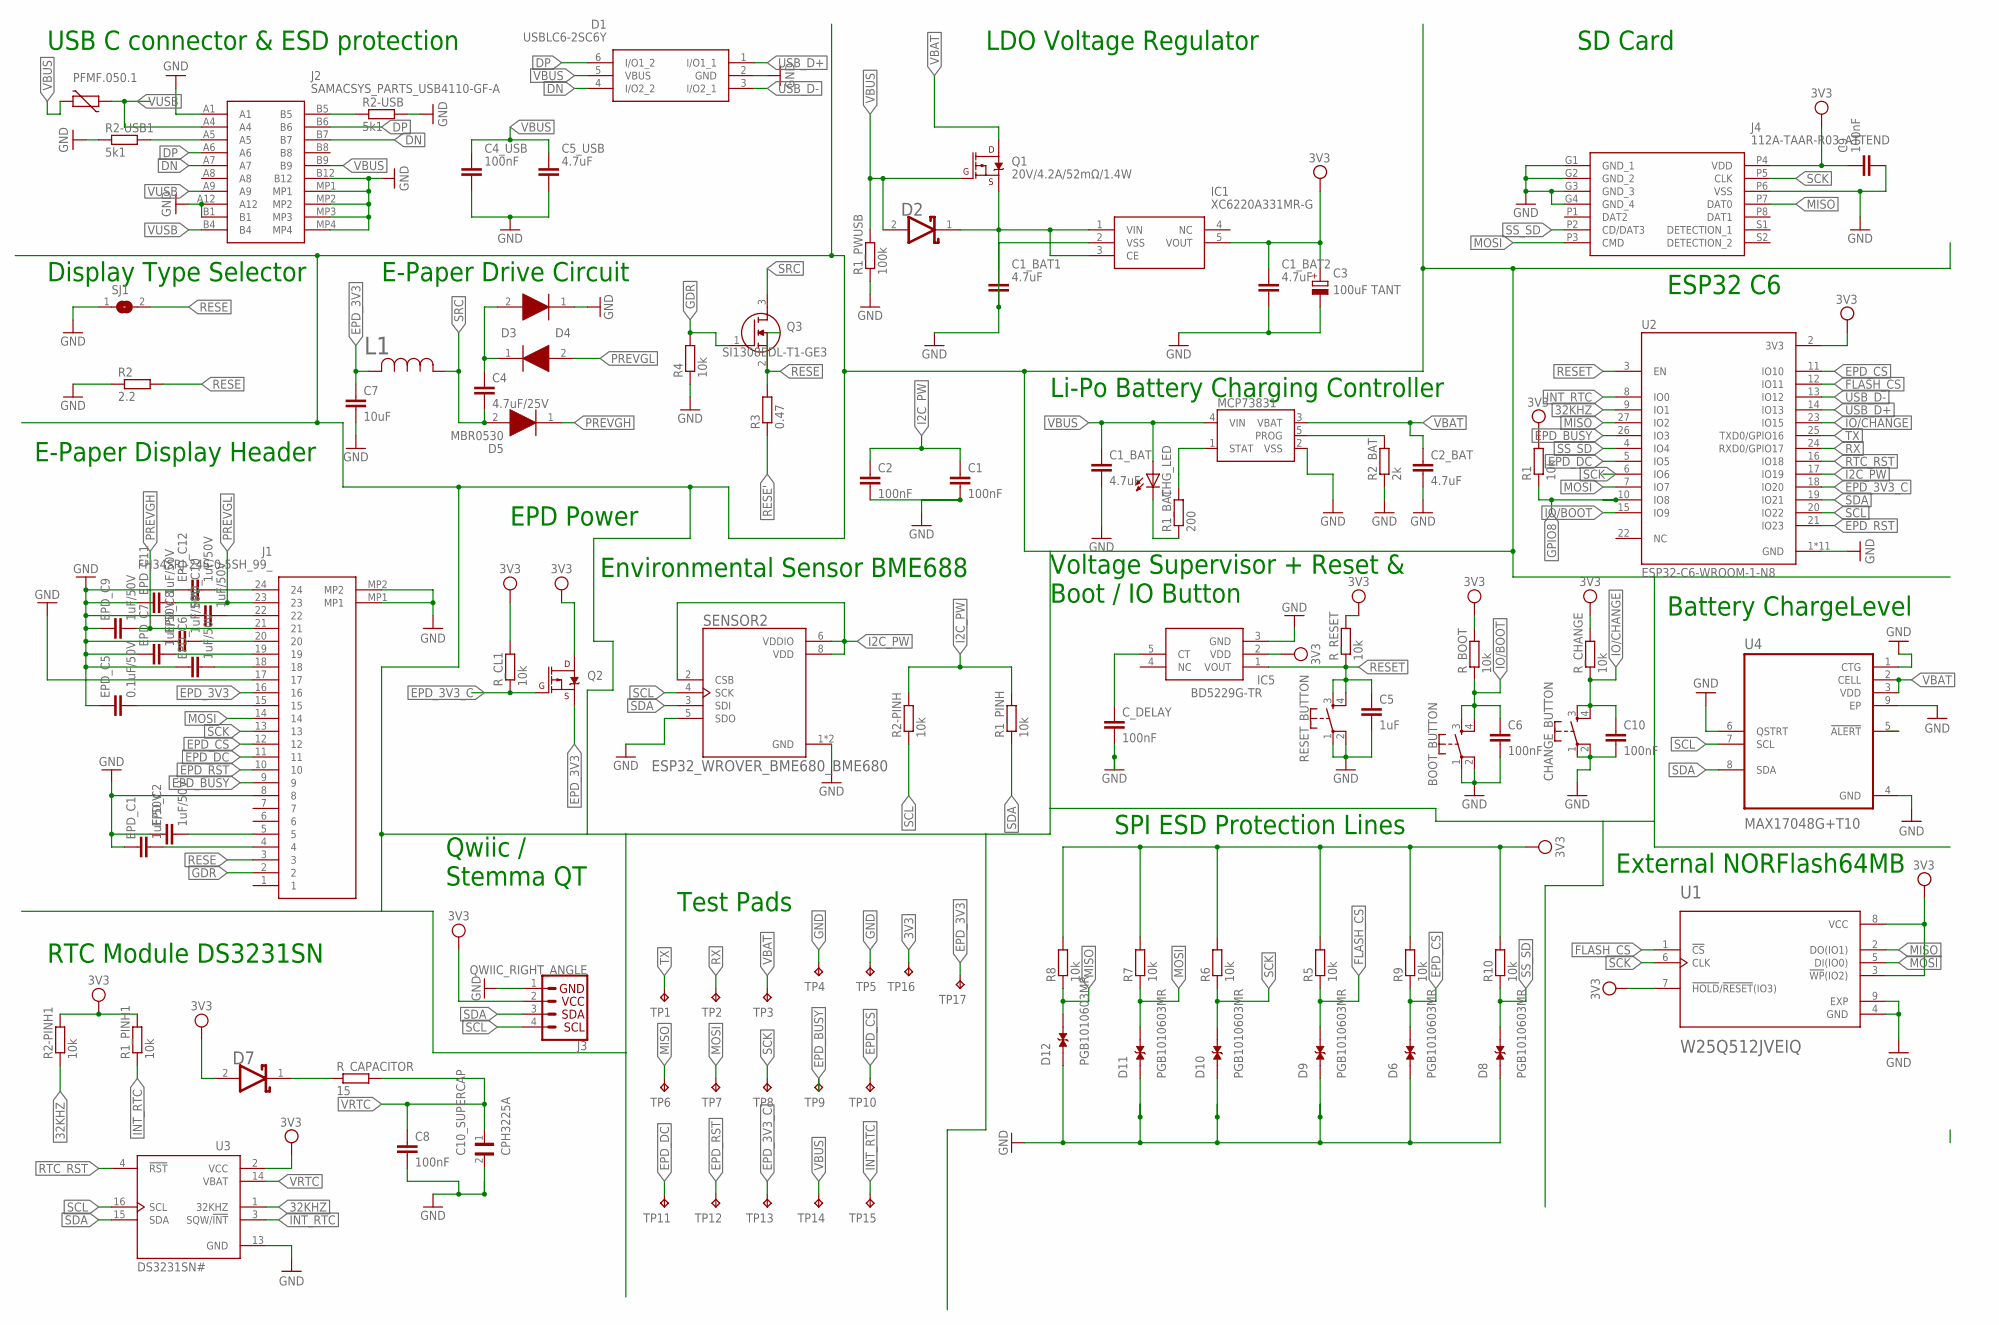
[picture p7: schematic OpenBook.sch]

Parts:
BOOT_BUTTON: BUTTON_CUSYOMV1; MYBUTTON
C1, C2, C6, C10: 100nF; ESP32_WROVER_EAGLE-LTSPICE_C0402
C1_BAT, C2_BAT: 4.7uF; ESP32_WROVER_EAGLE-LTSPICE_C0402
C1_BAT1, C5_USB: 4.7uF; CAPC1005X60
C1_BAT2: 4.7uF; CAPM3216X180
C3: 100uF TANT; CAPMP3216X180N
C4: 4.7uF/25V; EAGLE-LTSPICE_C0402
C4_USB, C9: 100nF; CAPC1005X60
C5: 1uF; ESP32_WROVER_EAGLE-LTSPICE_C0402
C7: 10uF; EAGLE-LTSPICE_C0402
C8: 100nF; EAGLE-LTSPICE_C0402
C10_SUPERCAP: CPH3225A; CAPCP3225X100N
CHANGE_BUTTON: BUTTON_CUSYOMV1; MYBUTTON
CHG_LED: ADAFRUIT_LEDCHIP-LED0603; ADAFRUIT_CHIP-LED0603
C_DELAY: 100nF; ESP32_WROVER_EAGLE-LTSPICE_C0402
D1: USBLC6-2SC6Y; SOT95P280X145-6N
D2, D7: ESP32_WROVER_AVX---SD0805S020S1R0_AVX_SD0805S020S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; ESP32_WROVER_AVX---SD0805S020S1R0_AVX_SD0805S020S1R0_0
D3, D4, D5: MBR0530; SOD3716X135N
D6, D8, D9, D10, D11, D12: PGB1010603MR; DIOC1608X36N
EPD_C1, EPD_C2, EPD_C6, EPD_C7, EPD_C8, EPD_C9, EPD_C10, EPD_C11, EPD_C12: 1uF/50V; ESP32_WROVER_EAGLE-LTSPICE_C0402
EPD_C5: 0.1uF/50V; ESP32_WROVER_EAGLE-LTSPICE_C0402
IC1: XC6220A331MR-G; SOT95P280X120-5N
IC5: BD5229G-TR; SOT95P280X125-5N
J1: FH34SRJ-24S-0.5SH_99_; FH34SRJ24S05SH99
J2: SAMACSYS_PARTS_USB4110-GF-A; SAMACSYS_PARTS_USB4110GFA
J3: QWIIC_RIGHT_ANGLE; JST04_1MM_RA
J4: 112A-TAAR-R03_ATTEND; 112ATAARR03ATTEND
L1: 68uH; IND_4828-WE-TPC_WRE
MCP73831: ESP32_WROVER_SPARKFUN-IC-POWER_MCP73831; ESP32_WROVER_SPARKFUN-IC-POWER_SOT23-5
PFMF.050.1: ESP32C6_VARISTORCN1812; ESP32C6_VARISTOR_CT/CN1812
Q1, Q2: 20V/4.2A/52mΩ/1.4W; ESP32_WROVER_SPARKFUN-DISCRETESEMI_SOT23-3
Q3: SI1308EDL-T1-GE3; SOT65P210X110-3N
R1, R1_PINH, R1_PINH1, R2-PINH, R2-PINH1, R4, R5, R6, R7, R8, R9, R10: 10k; ESP32_WROVER_EAGLE-LTSPICE_R0402
R1_BAT: 200; ESP32_WROVER_EAGLE-LTSPICE_R0402
R1_PWUSB: 100k; ESP32_WROVER_EAGLE-LTSPICE_R0402
R2: 2.2; ESP32_WROVER_EAGLE-LTSPICE_R0402
R2-USB, R2-USB1: 5k1; ESP32_WROVER_EAGLE-LTSPICE_R0402
R2_BAT: 2k; ESP32_WROVER_EAGLE-LTSPICE_R0402
R3: 0.47; ESP32_WROVER_EAGLE-LTSPICE_R0402
RESET_BUTTON: BUTTON_CUSYOMV1; MYBUTTON
R_BOOT: 10k; ESP32_WROVER_EAGLE-LTSPICE_R0402
R_CAPACITOR: 15; ESP32_WROVER_EAGLE-LTSPICE_R0402
R_CHANGE: 10k; ESP32_WROVER_EAGLE-LTSPICE_R0402
R_CL1: 10k; ESP32_WROVER_EAGLE-LTSPICE_R0402
R_RESET: 10k; ESP32_WROVER_EAGLE-LTSPICE_R0402
SENSOR2: ESP32_WROVER_BME680_BME680; ESP32_WROVER_BME680_PSON80P300X300X100-8N
SJ1: SJ
TP1, TP2, TP3, TP4, TP5, TP6, TP7, TP8, TP9, TP10, TP11, TP12, TP13, TP14, TP15, TP16, TP17: TPB1,27; B1,27
U1: W25Q512JVEIQ; SON127P600X800X80-9N
U2: ESP32-C6-WROOM-1-N8; XCVR_ESP32-C6-WROOM-1-N8
U3: DS3231SN#; SOIC127P1032X265-16N
U4: MAX17048G+T10; SON50P200X200X80-9N

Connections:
3V3: C1_BAT2.1, C3.1 (+), C9.1, D7.2 (ANODE), IC1.5 (VOUT), IC5.2 (VDD), J3.2, J4.P4 (VDD), Q2.3 (D), R1.2, R1_PINH1.2, R2-PINH1.2, R5.2, R6.2, R7.2, R8.2, R9.2, R10.2, R_BOOT.2, R_CHANGE.2, R_CL1.2, R_RESET.2, TP16.TP, U1.3 (!WP!(IO2)), U1.7 (!HOLD!/!RESET!(IO3)), U1.8 (VCC), U2.2 (3V3), U3.2 (VCC)
32KHZ: R2-PINH1.1, U2.9 (IO1), U3.1 (32KHZ)
DN: D1.4 (I/O2_2), J2.A7, J2.B7
DP: D1.6 (I/O1_2), J2.A6, J2.B6
EPD_3V3: C7.1, J1.16, L1.2, Q2.2 (S), TP17.TP
EPD_3V3_C: Q2.1 (G), R_CL1.1, TP13.TP, U2.18 (IO20)
EPD_BUSY: J1.9, TP9.TP, U2.26 (IO3)
EPD_CS: D6.2, J1.12, R9.1, TP10.TP, U2.11 (IO10)
EPD_DC: J1.11, TP11.TP, U2.5 (IO5)
EPD_RST: J1.10, TP12.TP, U2.21 (IO23)
FLASH_CS: D9.2, R5.1, U1.1 (!CS), U2.12 (IO11)
GDR: J1.2, Q3.1 (G), R4.2
GND: BOOT_BUTTON.1, BOOT_BUTTON.2, C1.2, C1_BAT.2, C1_BAT1.2, C1_BAT2.2, C2.2, C2_BAT.2, C3.2 (-), C4_USB.2, C5.2, C5_USB.2, C6.2, C7.2, C8.2, C9.2, C10.2, C10_SUPERCAP.2, CHANGE_BUTTON.1, CHANGE_BUTTON.2, C_DELAY.2, D1.2 (GND), D3.1 (K), D6.1, D8.1, D9.1, D10.1, D11.1, D12.1, EPD_C1.1, EPD_C2.1, EPD_C5.1, EPD_C6.1, EPD_C7.1, EPD_C8.1, EPD_C9.1, EPD_C10.1, EPD_C11.1, EPD_C12.1, IC1.2 (VSS), IC5.3 (GND), J1.8, J1.17, J1.MP1, J1.MP2, J2.A1, J2.A12, J2.B1, J2.B12, J2.MP1, J2.MP2, J2.MP3, J2.MP4, J3.1, J4.G1 (GND_1), J4.G2 (GND_2), J4.G3 (GND_3), J4.G4 (GND_4), J4.P6 (VSS), MCP73831.2 (VSS), R1_PWUSB.1, R2.1, R2-USB.2, R2-USB1.1, R2_BAT.1, R4.1, RESET_BUTTON.1, RESET_BUTTON.2, SENSOR2.1 (GND), SENSOR2.5 (SDO), SENSOR2.7 (GND), SJ1.1, TP4.TP, TP5.TP, U1.4 (GND), U1.9 (EXP), U2.1 (GND), U2.28 (GND), U2.29_1 (GND), U2.29_2 (GND), U2.29_3 (GND), U2.29_4 (GND), U2.29_5 (GND), U2.29_6 (GND), U2.29_7 (GND), U2.29_8 (GND), U2.29_9 (GND), U3.13 (GND), U4.1 (CTG), U4.4 (GND), U4.6 (QSTRT), U4.9 (EP)
GPIO8: R1.1, U2.10 (IO8)
I2C_PW: C1.1, C2.1, R1_PINH.2, R2-PINH.2, SENSOR2.2 (CSB), SENSOR2.6 (VDDIO), SENSOR2.8 (VDD), U2.17 (IO19)
INT_RTC: R1_PINH1.1, TP15.TP, U2.8 (IO0), U3.3 (SQW/!INT)
IO/BOOT: BOOT_BUTTON.3, BOOT_BUTTON.4, C6.1, R_BOOT.1, U2.15 (IO9)
IO/CHANGE: C10.1, CHANGE_BUTTON.3, CHANGE_BUTTON.4, R_CHANGE.1, U2.23 (IO15)
MISO: D12.2, J4.P7 (DAT0), R8.1, TP6.TP, U1.2 (DO(IO1)), U2.27 (IO2)
MOSI: D11.2, J1.14, J4.P3 (CMD), R7.1, TP7.TP, U1.5 (DI(IO0)), U2.7 (IO7)
unnamed: C1_BAT1.1, D2.1 (CATHODE), IC1.1 (VIN), IC1.3 (CE), Q1.2 (S)
unnamed: J2.A5, R2-USB1.2
unnamed: C4.1, D3.2 (A), D4.1 (K)
unnamed: MCP73831.5 (PROG), R2_BAT.2
unnamed: MCP73831.1 (STAT), R1_BAT.2
unnamed: CHG_LED.C, R1_BAT.1
unnamed: EPD_C1.2, J1.4
unnamed: EPD_C2.2, J1.5
unnamed: EPD_C5.2, J1.15
unnamed: EPD_C6.2, J1.18
unnamed: EPD_C7.2, J1.19
unnamed: EPD_C8.2, J1.20
unnamed: C_DELAY.1, IC5.5 (CT)
unnamed: EPD_C10.2, J1.22
unnamed: D7.1 (CATHODE), R_CAPACITOR.1
unnamed: EPD_C12.2, J1.24
unnamed: J2.B5, R2-USB.1
PREVGH: D5.1 (K), EPD_C9.2, J1.21
PREVGL: D4.2 (A), EPD_C11.2, J1.23
RESE: J1.3, Q3.2 (S), R2.2, R3.2, SJ1.2
RESE': R3.1
RESET: C5.1, IC5.1 (VOUT), RESET_BUTTON.3, RESET_BUTTON.4, R_RESET.1, U2.3 (EN)
RTC_RST: U2.16 (IO18), U3.4 (!RST)
RX: TP2.TP, U2.24 (RXD0/GPIO17)
SCK: D10.2, J1.13, J4.P5 (CLK), R6.1, TP8.TP, U1.6 (CLK), U2.6 (IO6)
SCL: J3.4, R2-PINH.1, SENSOR2.4 (SCK), U2.20 (IO22), U3.16 (SCL), U4.5 (!ALERT), U4.7 (SCL)
SDA: J3.3, R1_PINH.1, SENSOR2.3 (SDI), U2.19 (IO21), U3.15 (SDA), U4.8 (SDA)
SRC: C4.2, D5.2 (A), L1.1, Q3.3 (D)
SS_SD: D8.2, J4.P2 (CD/DAT3), R10.1, U2.4 (IO4)
TX: TP1.TP, U2.25 (TXD0/GPIO16)
USB_D+: D1.1 (I/O1_1), U2.14 (IO13)
USB_D-: D1.3 (I/O2_1), U2.13 (IO12)
VBAT: C2_BAT.1, MCP73831.3 (VBAT), Q1.3 (D), TP3.TP, U4.2 (CELL), U4.3 (VDD)
VBUS: C1_BAT.1, C4_USB.1, C5_USB.1, CHG_LED.A, D1.5 (VBUS), D2.2 (ANODE), J2.B9, MCP73831.4 (VIN), PFMF.050.1.2, Q1.1 (G), R1_PWUSB.2, TP14.TP
VRTC: C8.1, C10_SUPERCAP.1, R_CAPACITOR.2, U3.14 (VBAT)
VUSB: J2.A4, J2.A9, J2.B4, PFMF.050.1.1

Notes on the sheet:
USB C connector & ESD protection
LDO Voltage Regulator
SD Card
Display Type Selector
E-Paper Drive Circuit
Li-Po Battery Charging Controller
E-Paper Display Header
EPD Power
Environmental Sensor BME688
Voltage Supervisor + Reset & Boot / IO Button
Battery ChargeLevel
RTC Module DS3231SN
Test Pads
SPI ESD Protection Lines
External NORFlash64MB
Qwiic / Stemma QT
ESP32 C6

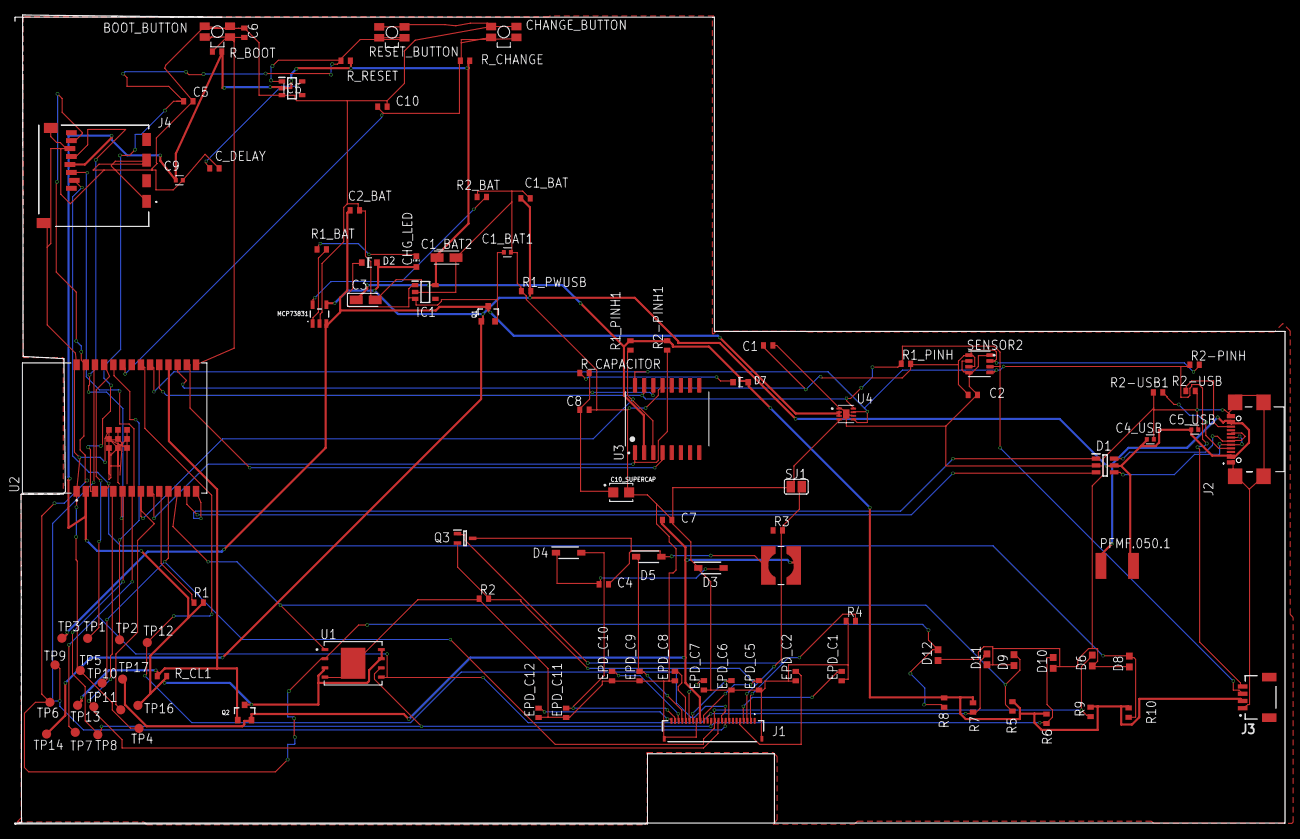
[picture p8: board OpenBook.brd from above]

Board: 2 copper layers, 175.6 x 111.8 mm, 103 parts (0 on the bottom side), 55 nets.

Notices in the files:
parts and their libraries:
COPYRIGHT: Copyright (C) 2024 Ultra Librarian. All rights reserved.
